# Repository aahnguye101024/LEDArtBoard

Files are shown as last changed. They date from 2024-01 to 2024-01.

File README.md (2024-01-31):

# LEDArtBoard
This project is an ESP32 that can control a huge array of leds in order to generate pixel art. With a single 12V input, you can power on an ESP32 and huge array of leds (at very low current draw for each led). It was intended as a gift for a friend, where I could upload an array of values with specific RGB codes to display that color in that specific led location on the array. It was also to test JLCPCB's new at the time feature to assemble PCBs for a super low cost.

# Main Board
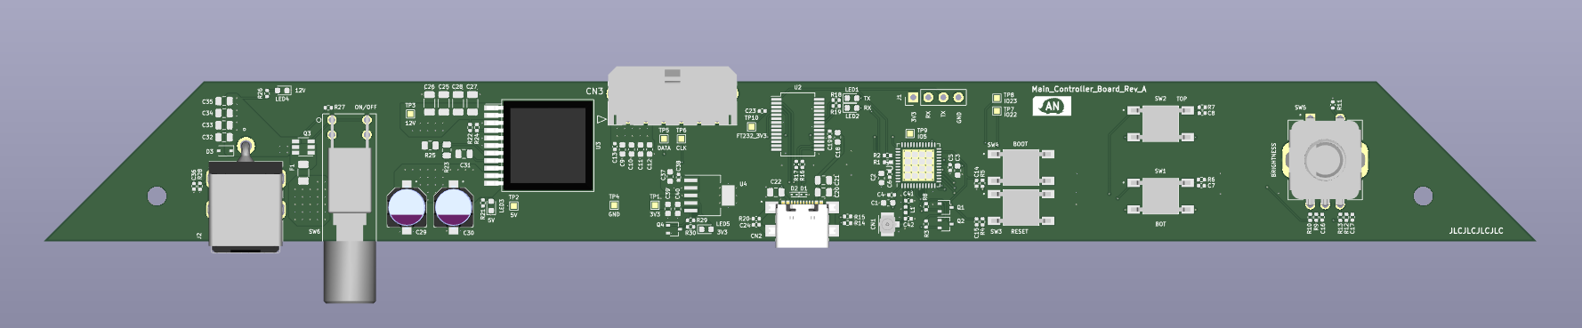
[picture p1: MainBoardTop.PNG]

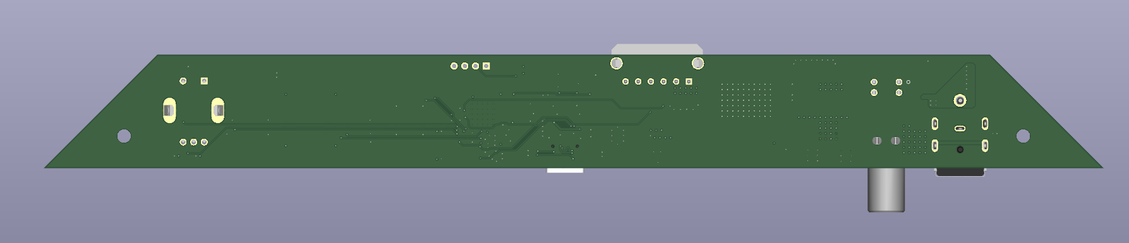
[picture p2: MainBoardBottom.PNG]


# LED Board
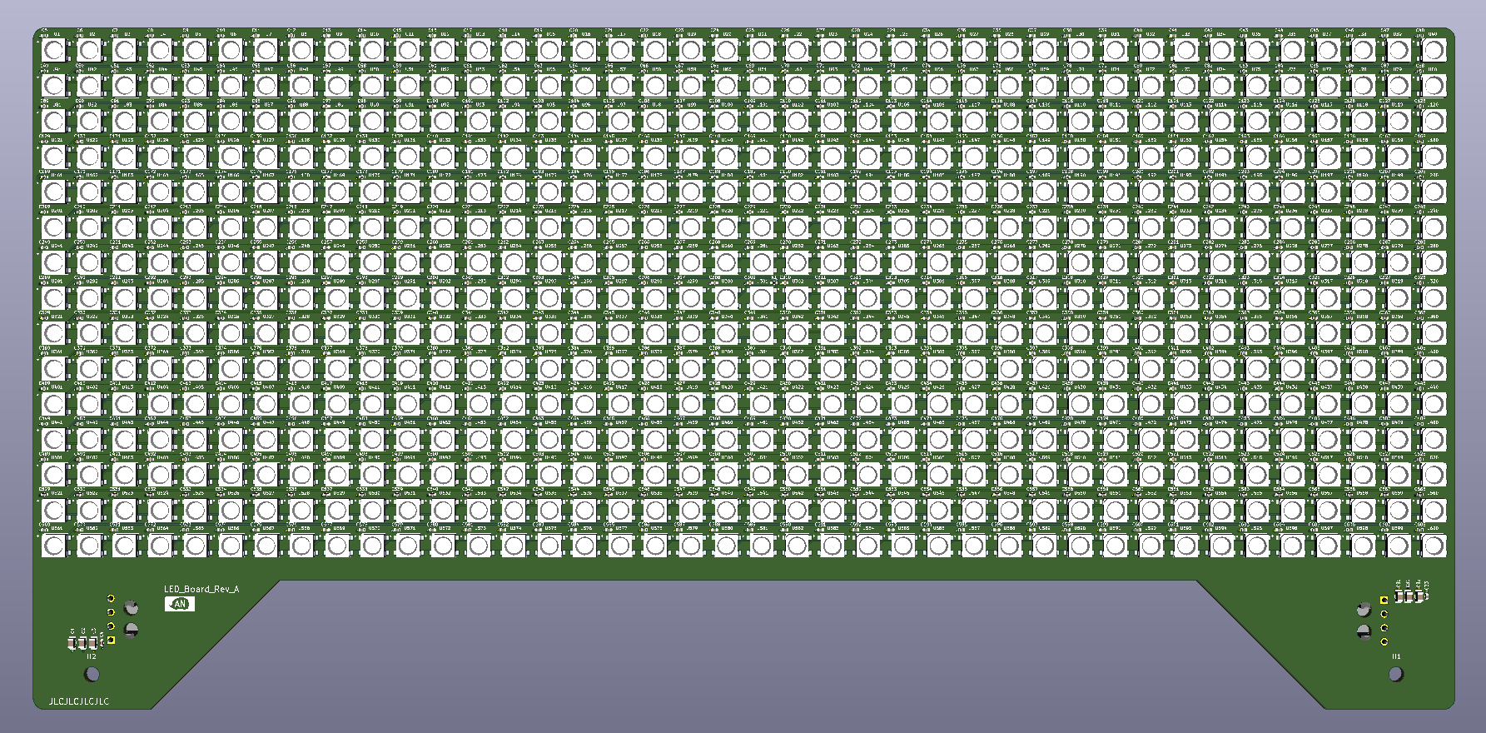
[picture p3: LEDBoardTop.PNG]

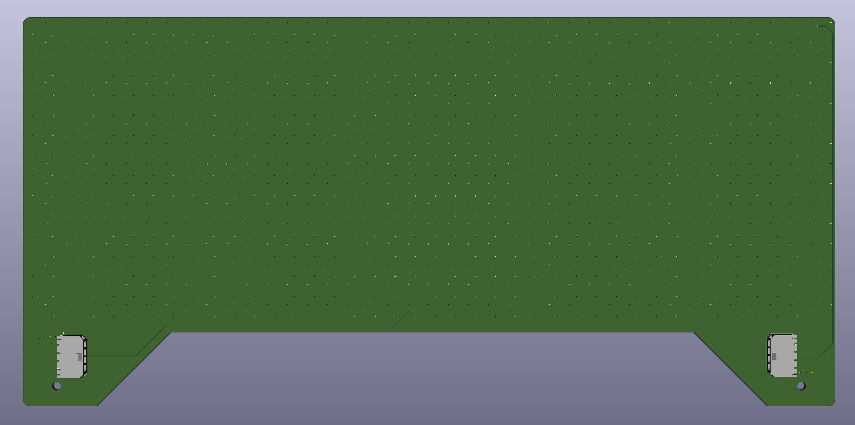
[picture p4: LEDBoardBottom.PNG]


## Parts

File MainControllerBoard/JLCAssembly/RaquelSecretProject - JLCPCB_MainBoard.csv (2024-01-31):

Comment | Designator | Footprint | JLCPCB Part #（optional）
ESP32-PICO-D4 | U1 | QFN-48_EP_7.0x7.0x0.5P | C193707
2.2uF | C1, C2, C3, C37, C39, C40, | 0603 | C23630
0.1uF | C4, C5, C6, C7, C8, C13, C14, C19, C23, C24, C36, C38, | 0402 | C1525
22uF | C9, C10, C11, C12, | 0603 | C59461
1uF | C15, | 0402 | C52923
0.01uF | C16, C17, | 0402 | C15195
4.7uF | C18, | 0603 | C19666
10uF | C20, C21, C22, C32, C33, C34, C35, | 0805 | C440198
22uF | C25, C26, C27, C28, | 1206 | C1934
0.47uF | C31, | 0805 | C13967
2.7pF | C41, | 0402 | C1561
10k | R3, R4, R8, R9, R10, R12, R13, | 0402 | C25744
4.7k | R5, R6, R7, R11, | 0402 | C25900
5.1k | R14, R15, | 0402 | C25905
330 | R18, R19, R20, R28, R30, | 0402 | C25104
100k | R22, R27, R29, | 0402 | C25741
22k | R24, | 0402 | C25768
0 | R1, R2, R16, R17, | 0402 | C17168

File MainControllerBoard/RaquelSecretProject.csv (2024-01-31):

Source: | C:\Users\AaronN\Desktop\Personal\PersonalProjects\RaquelSecretProject\MainControllerBoard\RaquelSecretProject.sch
Date: | 1/8/2022 8:56:27 PM
Tool: | Eeschema (5.1.10)-1
Generator: | C:\Program Files\KiCad\bin\scripting\plugins/AaronsFavoriteBOMScript.py
Component Count: | 113
Ref | Qnty | Value | Cmp name | Description | Manufacturer | Part Number
C1, C2, C3, C37, C39, C40, | 6 | 2.2uF | 2.2uF | CAP CER 2.2UF 10V X5R 0603 | Samsung Electro-Mechanics | 1276-1085-1-ND
C4, C5, C6, C7, C8, C13, C14, C19, C23, C24, C36, C38, | 12 | 0.1uF | 0.1uF | CAP CER 0.1UF 25V X5R 0402 | Samsung Electro-Mechanics | 1276-1043-1-ND
C9, C10, C11, C12, | 4 | 22uF | 22uF | CAP CER 22UF 10V X5R 0603 | Samsung Electro-Mechanics | 1276-1274-1-ND
C15, | 1 | 1uF | 1uF | CAP CER 1UF 10V X5R 0402 | Samsung Electro-Mechanics | 1276-1076-1-ND
C16, C17, | 2 | 0.01uF | 0.01uF | CAP CER 10000PF 16V X5R 0402 | KYOCERA AVX | 478-0402YD103KAT2ACT-ND
C18, | 1 | 4.7uF | 4.7uF | CAP CER 4.7UF 16V X5R 0603 | Samsung Electro-Mechanics | 1276-1784-1-ND
C20, C21, C22, C32, C33, C34, C35, | 7 | 10uF | 10uF | CAP CER 10UF 16V X5R 0805 | Samsung Electro-Mechanics | 1276-2893-1-ND
C25, C26, C27, C28, | 4 | 22uF_1206 | 22uF_1206 | CAP CER 22UF 25V X5R 1206 | Samsung Electro-Mechanics | 1276-3047-1-ND
C29, C30, | 2 | 270uF | 270uF | CAP ALUM POLY 270UF 20% 16V SMD | Panasonic Electronic Components | PCE5081CT-ND
C31, | 1 | 0.47uF | 0.47uF | CAP CER 0.47UF 25V X7R 0805 | Samsung Electro-Mechanics | 1276-1074-1-ND
C41, | 1 | 2.7pF | 2.7pF | CAP CER 2.7PF 50V C0G/NPO 0402 | YAGEO | 311-1005-1-ND
C42, | 1 | 2pF | 2pF | CAP CER 2PF 50V C0G/NPO 0402 | YAGEO | 311-1006-1-ND
CN1, | 1 | 1909763-1 | 1909763-1 | CONN UMCC JACK STR 50OHM SMD | TE Connectivity AMP Connectors | A118077CT-ND
CN2, | 1 | USB4110-GF-A_REVB | USB4110-GF-A_REVB | SMD USB 2.0-only Type-C Receptacle connector | GCT | 2073-USB4110-GF-A-1-ND
CN3, | 1 | 0436500603 | 0436500603 | Microfit CONN HEADER R/A 6POS 3MM | Molex | WM1874-ND
D1, D2, | 2 | ESD7951ST5G | ESD7951ST5G | TVS DIODE 5VWM 12.9VC SOD923 | onsemi | ESD7951ST5GOSCT-ND
D3, | 1 | ESD12VD3-TP | ESD12VD3-TP | TVS DIODE 12VWM 33VC SOD323 | Micro Commercial Co | ESD12VD3-TPMSCT-ND
F1, | 1 | C1F_7 | C1F_7 | FUSE 7.0A 125VAC FAST 1206 | Bel Fuse Inc. | 507-1888-1-ND
H1, H2, | 2 | MountingHole | MountingHole | Mounting Hole without connection
J1, | 1 | Conn_01x04 | Conn_01x04 | Generic connector, single row, 01x04, script generated (kicad-library-utils/schlib/autogen/connector/)
J2, | 1 | PJ-080BH | PJ-080BH | CONN PWR JACK 2.5X5.5MM SOLDER | CUI Devices | CP-080BHCT-ND
L1, | 1 | LQG15HS2N7S02D | LQG15HS2N7S02D | FIXED IND 2.7NH 800MA 150MOHM SM | Murata Electronics | 490-2615-1-ND
LED1, LED3, LED4, LED5, | 4 | SML-D12P8WT86 | SML-D12P8WT86 | LED GREEN DIFFUSED 0603 SMD | Rohm Semiconductor | 511-1579-1-ND
LED2, | 1 | SML-D12U1WT86 | SML-D12U1WT86 | LED RED DIFFUSED 0603 SMD | Rohm Semiconductor | SML-D12U1WT86CT-ND
Q1, Q2, | 2 | BC846W,115 | BC846W,115 | TRANS NPN 65V 100MA SOT323 | Nexperia USA Inc. | 1727-4850-1-ND
Q3, | 1 | SI3469DV-T1-E3 | SI3469DV-T1-E3 | MOSFET P-CH 20V 5A 6TSOP | Vishay Siliconix | SI3469DV-T1-E3CT-ND
Q4, | 1 | DMN67D8LW-13 | DMN67D8LW-13 | MOSFET N-CH 60V 240MA SOT323 | Diodes Incorporated | DMN67D8LW-13DICT-ND
R1, R2, R16, R17, | 4 | 0 | 0 | RES 0 OHM JUMPER 1/16W 0402 | Stackpole Electronics Inc | RMCF0402ZT0R00CT-ND
R3, R4, R8, R9, R10, R12, R13, | 7 | 10k | 10k | RES 10K OHM 1% 1/16W 0402 | Stackpole Electronics Inc | RMCF0402FT10K0CT-ND
R5, R6, R7, R11, | 4 | 4.7k | 4.7k | RES 4.7K OHM 1% 1/16W 0402 | Stackpole Electronics Inc | RMCF0402FT4K70CT-ND
R14, R15, | 2 | 5.1k | 5.1k | RES 5.1K OHM 1% 1/16W 0402 | YAGEO | 311-5.10KLRCT-ND
R18, R19, R20, R28, R30, | 5 | 330 | 330 | RES 330 OHM 1% 1/16W 0402 | YAGEO | 311-330LRCT-ND
R21, | 1 | 820 | 820 | RES 820 OHM 1% 1/16W 0402 | Stackpole Electronics Inc | RMCF0402FT820RCT-ND
R22, R27, R29, | 3 | 100k | 100k | RES SMD 100 KOHM 1% 1/16W 0402 | Delta Electronics/Cyntec | 2037-PFR05S-104-FNHCT-ND
R23, | 1 | 5.62k | 5.62k | RES 5.62K OHM 1% 1/8W 0805 | Stackpole Electronics Inc | RMCF0805FT5K62CT-ND
R24, | 1 | 22k | 22k | RES SMD 22K OHM 1% 1/16W 0402 | Bourns Inc. | CR0402-FX-2202GLFCT-ND
R25, | 1 | 1.07k | 1.07k | RES 1.07K OHM 1% 1/8W 0805 | YAGEO | 311-1.07KCRCT-ND
R26, | 1 | 3k | 3k | RES 3K OHM 1% 1/16W 0402 | Stackpole Electronics Inc | RMCF0402FT3K00CT-ND
SW1, SW2, SW3, SW4, | 4 | FSM2JSMAA | FSM2JSMAA | SMD Momentary PushButton | FSM2JSMAA | 450-3355-ND
SW5, | 1 | PEC11R-4020F-S0024 | PEC11R-4020F-S0024 | ROTARY ENCODER MECHANICAL 24PPR | Bourns Inc. | PEC11R-4020F-S0024-ND
SW6, | 1 | PB400EEQR1BLK | PB400EEQR1BLK | Pushbutton Switch DPST Standard Through Hole, Right Angle | E-Switch | Ologic
TP1, | 1 | 3V3 | TestPoint | test point
TP2, | 1 | 5V | TestPoint | test point
TP3, | 1 | 12V | TestPoint | test point
TP4, | 1 | GND | TestPoint | test point
TP5, | 1 | DATA | TestPoint | test point
TP6, | 1 | CLK | TestPoint | test point
TP7, | 1 | IO22 | TestPoint | test point
TP8, | 1 | IO23 | TestPoint | test point
TP9, | 1 | IO5 | TestPoint | test point
TP10, | 1 | FT232_3V3 | TestPoint | test point
U1, | 1 | ESP32-PICO-D4 | ESP32-PICO-D4 |  | Espressif Systems | 1904-1029-1-ND
U2, | 1 | FT232RL | FT232RL | USB to Serial Interface, SSOP-28 | Ologic | Ologic
U3, | 1 | LMZ13610 | LMZ13610 | DC DC CONVERTER 0.8-6V 50W | Texas Instruments | Ologic
U4, | 1 | MCP1826T-3302E_DC | MCP1826T-3302E_DC | IC REG LINEAR 3.3V 1A SOT223-5 | Microchip Technology | Ologic

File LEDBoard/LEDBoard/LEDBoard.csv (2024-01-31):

Source: | C:\Users\AaronN\Desktop\Personal\PersonalProjects\RaquelSecretProject\LEDBoard\LEDBoard\LEDBoard.sch
Date: | 1/9/2022 12:14:57 AM
Tool: | Eeschema (5.1.10)-1
Generator: | C:\Program Files\KiCad\bin\scripting\plugins/AaronsFavoriteBOMScript.py
Component Count: | 1213
Ref | Qnty | Value | Cmp name | Description | Manufacturer | Part Number
C1, C2, C3, C30, C31, C32, | 6 | 10uF | 10uF | CAP CER 10UF 16V X5R 0805 | Samsung Electro-Mechanics | 1276-2893-1-ND
C4, C33, | 2 | 0.1uF | 0.1uF | CAP CER 0.1UF 25V X5R 0402 | Samsung Electro-Mechanics | 1276-1043-1-ND
C5, C6, C7, C8, C9, C10, C11, C12, C13, C14, C15, C16, C17, C18, C19, C20, C21, C22, C23, C24, C25, C26, C27, C28, C29, C34, C35, C36, C37, C38, C39, C40, C41, C42, C43, C44, C45, C46, C47, C48, C49, C50, C51, C52, C53, C54, C55, C56, C57, C58, C59, C60, C61, C62, C63, C64, C65, C66, C67, C68, C69, C70, C71, C72, C73, C74, C75, C76, C77, C78, C79, C80, C81, C82, C83, C84, C85, C86, C87, C88, C89, C90, C91, C92, C93, C94, C95, C96, C97, C98, C99, C100, C101, C102, C103, C104, C105, C106, C107, C108, C109, C110, C111, C112, C113, C114, C115, C116, C117, C118, C119, C120, C121, C122, C123, C124, C125, C126, C127, C128, C129, C130, C131, C132, C133, C134, C135, C136, C137, C138, C139, C140, C141, C142, C143, C144, C145, C146, C147, C148, C149, C150, C151, C152, C153, C154, C155, C156, C157, C158, C159, C160, C161, C162, C163, C164, C165, C166, C167, C168, C169, C170, C171, C172, C173, C174, C175, C176, C177, C178, C179, C180, C181, C182, C183, C184, C185, C186, C187, C188, C189, C190, C191, C192, C193, C194, C195, C196, C197, C198, C199, C200, C201, C202, C203, C204, C205, C206, C207, C208, C209, C210, C211, C212, C213, C214, C215, C216, C217, C218, C219, C220, C221, C222, C223, C224, C225, C226, C227, C228, C229, C230, C231, C232, C233, C234, C235, C236, C237, C238, C239, C240, C241, C242, C243, C244, C245, C246, C247, C248, C249, C250, C251, C252, C253, C254, C255, C256, C257, C258, C259, C260, C261, C262, C263, C264, C265, C266, C267, C268, C269, C270, C271, C272, C273, C274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 | 600 | 1uF | 1uF | CAP CER 1UF 10V X5R 0402 | Samsung Electro-Mechanics | 1276-1076-1-ND
CN1, CN2, | 2 | 0436500400 | 0436500400 | Microfit R/A CONN HEADER R/A 4POS 3MM | Molex | WM1862-ND
H1, H2, | 2 | MountingHole | MountingHole | Mounting Hole without connection
R1, | 1 | 0 | 0 | RES 0 OHM JUMPER 1/16W 0402 | Stackpole Electronics Inc | RMCF0402ZT0R00CT-ND
U1, U2, U3, U4, U5, U6, U7, U8, U9, U10, U11, U12, U13, U14, U15, U16, U17, U18, U19, U20, U21, U22, U23, U24, U25, U26, U27, U28, U29, U30, U31, U32, U33, U34, U35, U36, U37, U38, U39, U40, U41, U42, U43, U44, U45, U46, U47, U48, U49, U50, U51, U52, U53, U54, U55, U56, U57, U58, U59, U60, U61, U62, U63, U64, U65, U66, U67, U68, U69, U70, U71, U72, U73, U74, U75, U76, U77, U78, U79, U80, U81, U82, U83, U84, U85, U86, U87, U88, U89, U90, U91, U92, U93, U94, U95, U96, U97, U98, U99, U100, U101, U102, U103, U104, U105, U106, U107, U108, U109, U110, U111, U112, U113, U114, U115, U116, U117, U118, U119, U120, U121, U122, U123, U124, U125, U126, U127, U128, U129, U130, U131, U132, U133, U134, U135, U136, U137, U138, U139, U140, U141, U142, U143, U144, U145, U146, U147, U148, U149, U150, U151, U152, U153, U154, U155, U156, U157, U158, U159, U160, U161, U162, U163, U164, U165, U166, U167, U168, U169, U170, U171, U172, U173, U174, U175, U176, U177, U178, U179, U180, U181, U182, U183, U184, U185, U186, U187, U188, U189, U190, U191, U192, U193, U194, U195, U196, U197, U198, U199, U200, U201, U202, U203, U204, U205, U206, U207, U208, U209, U210, U211, U212, U213, U214, U215, U216, U217, U218, U219, U220, U221, U222, U223, U224, U225, U226, U227, U228, U229, U230, U231, U232, U233, U234, U235, U236, U237, U238, U239, U240, U241, U242, U243, U244, U245, U246, U247, U248, U249, U250, U251, U252, U253, U254, U255, U256, U257, U258, U259, U260, U261, U262, U263, U264, U265, U266, U267, U268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 | 600 | WS2812B | WS2812B | JLCPCB SMD,5x5mm Light Emitting Diodes (LED) ROHS | Worldsemi | C2761795

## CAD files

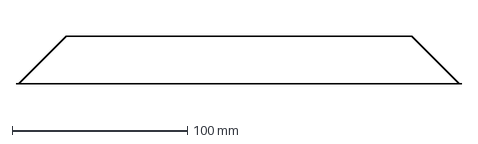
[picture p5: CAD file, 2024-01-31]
MainControllerBoard/MainControllerBoard.dxf
254.0 x 26.9 mm

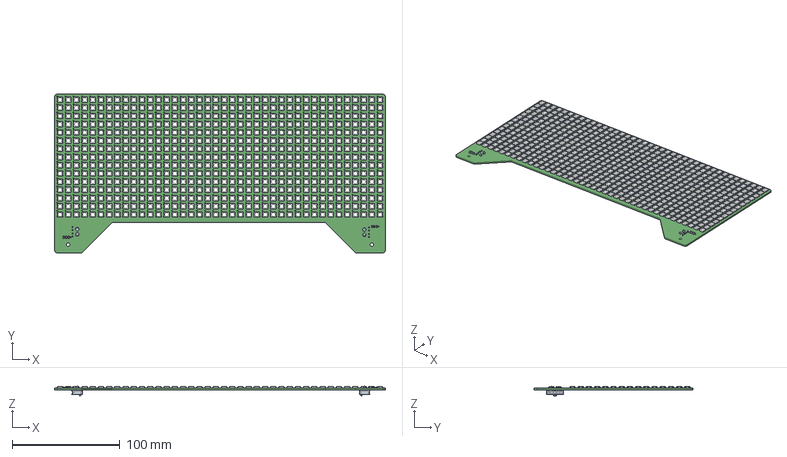
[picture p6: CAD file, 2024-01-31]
LEDBoard/LEDBoard/LEDBoard.step
307.3 x 147.3 x 8.90 mm

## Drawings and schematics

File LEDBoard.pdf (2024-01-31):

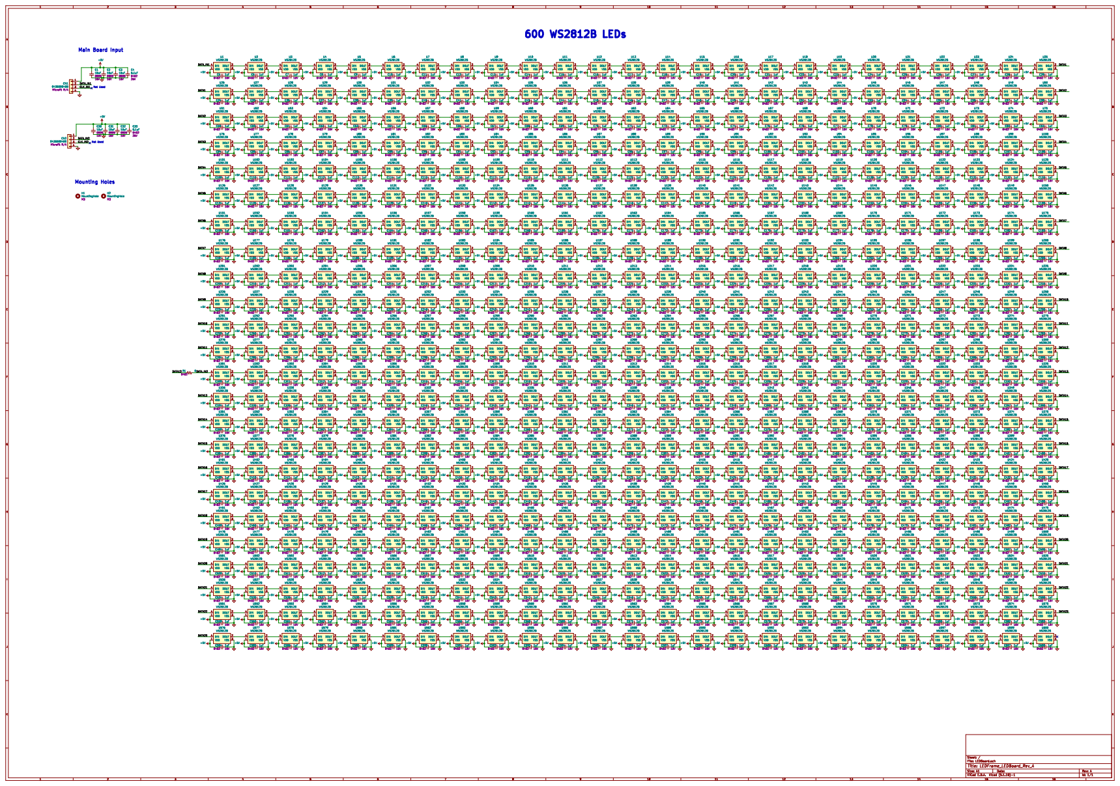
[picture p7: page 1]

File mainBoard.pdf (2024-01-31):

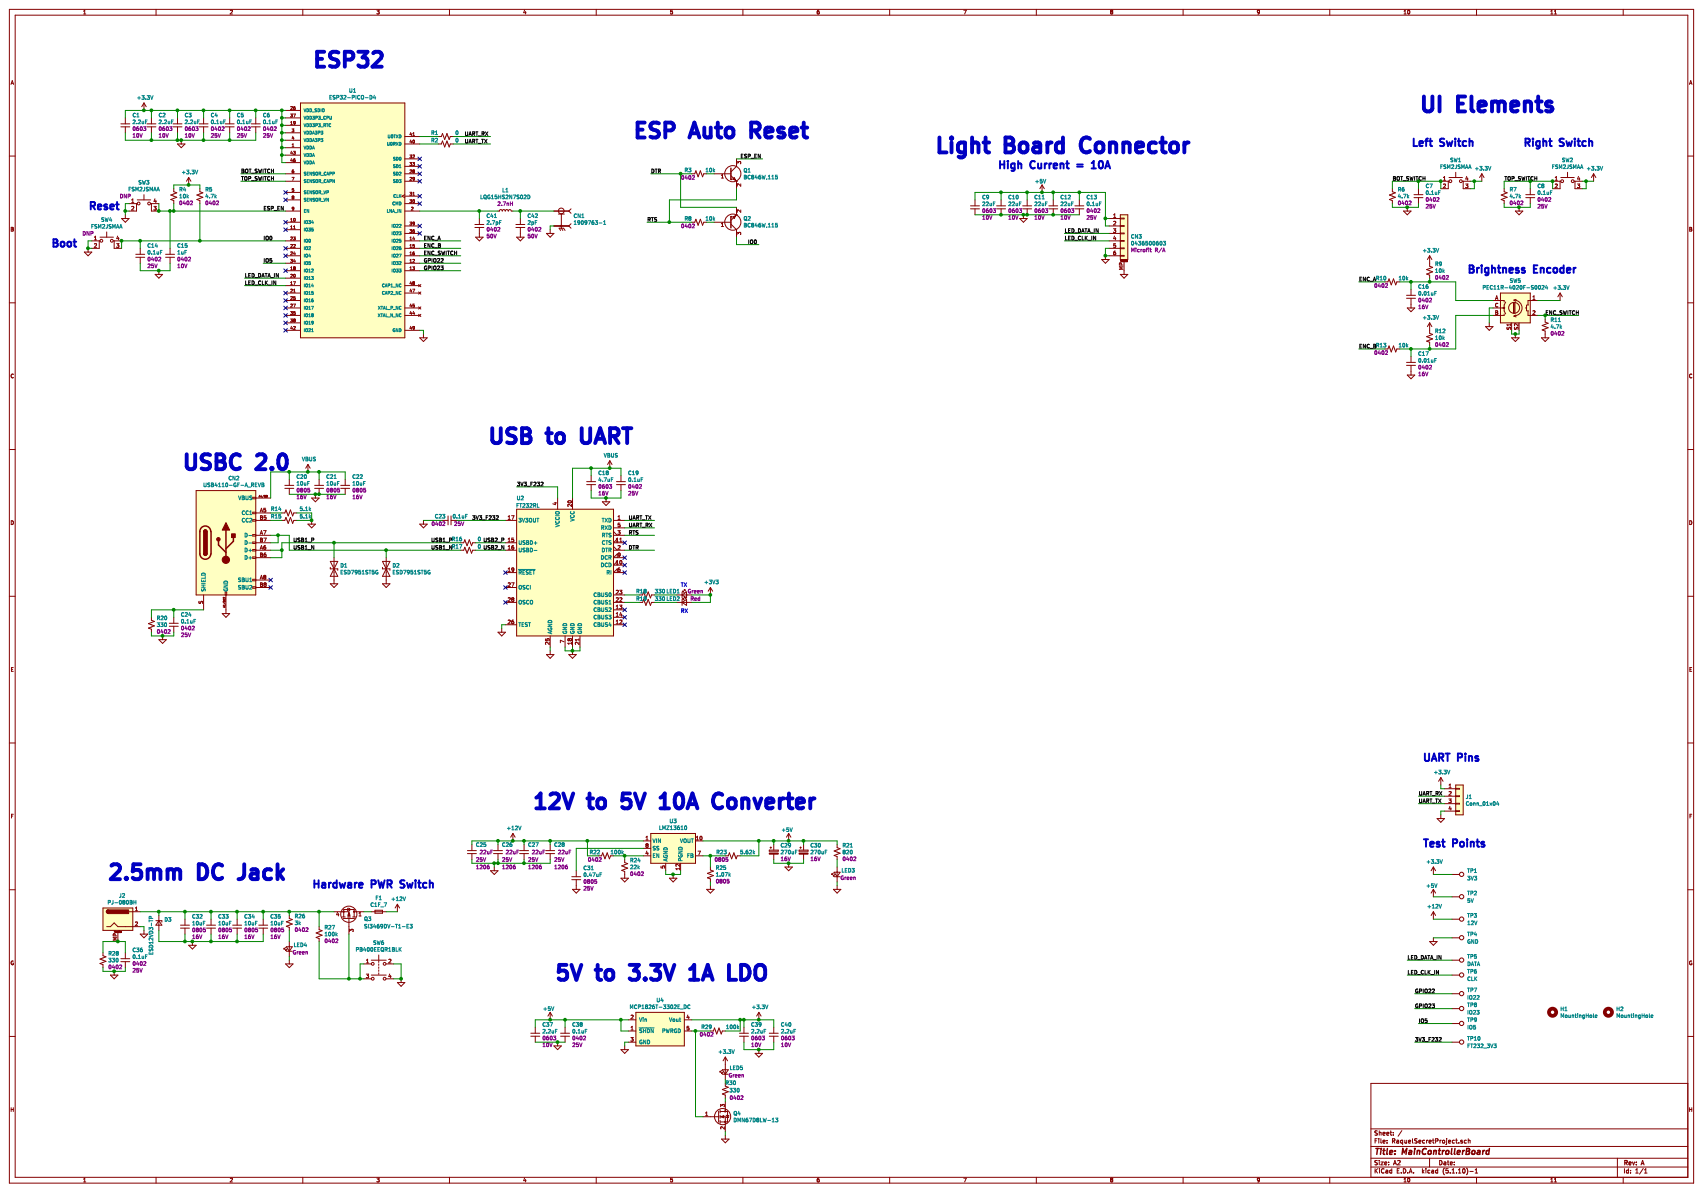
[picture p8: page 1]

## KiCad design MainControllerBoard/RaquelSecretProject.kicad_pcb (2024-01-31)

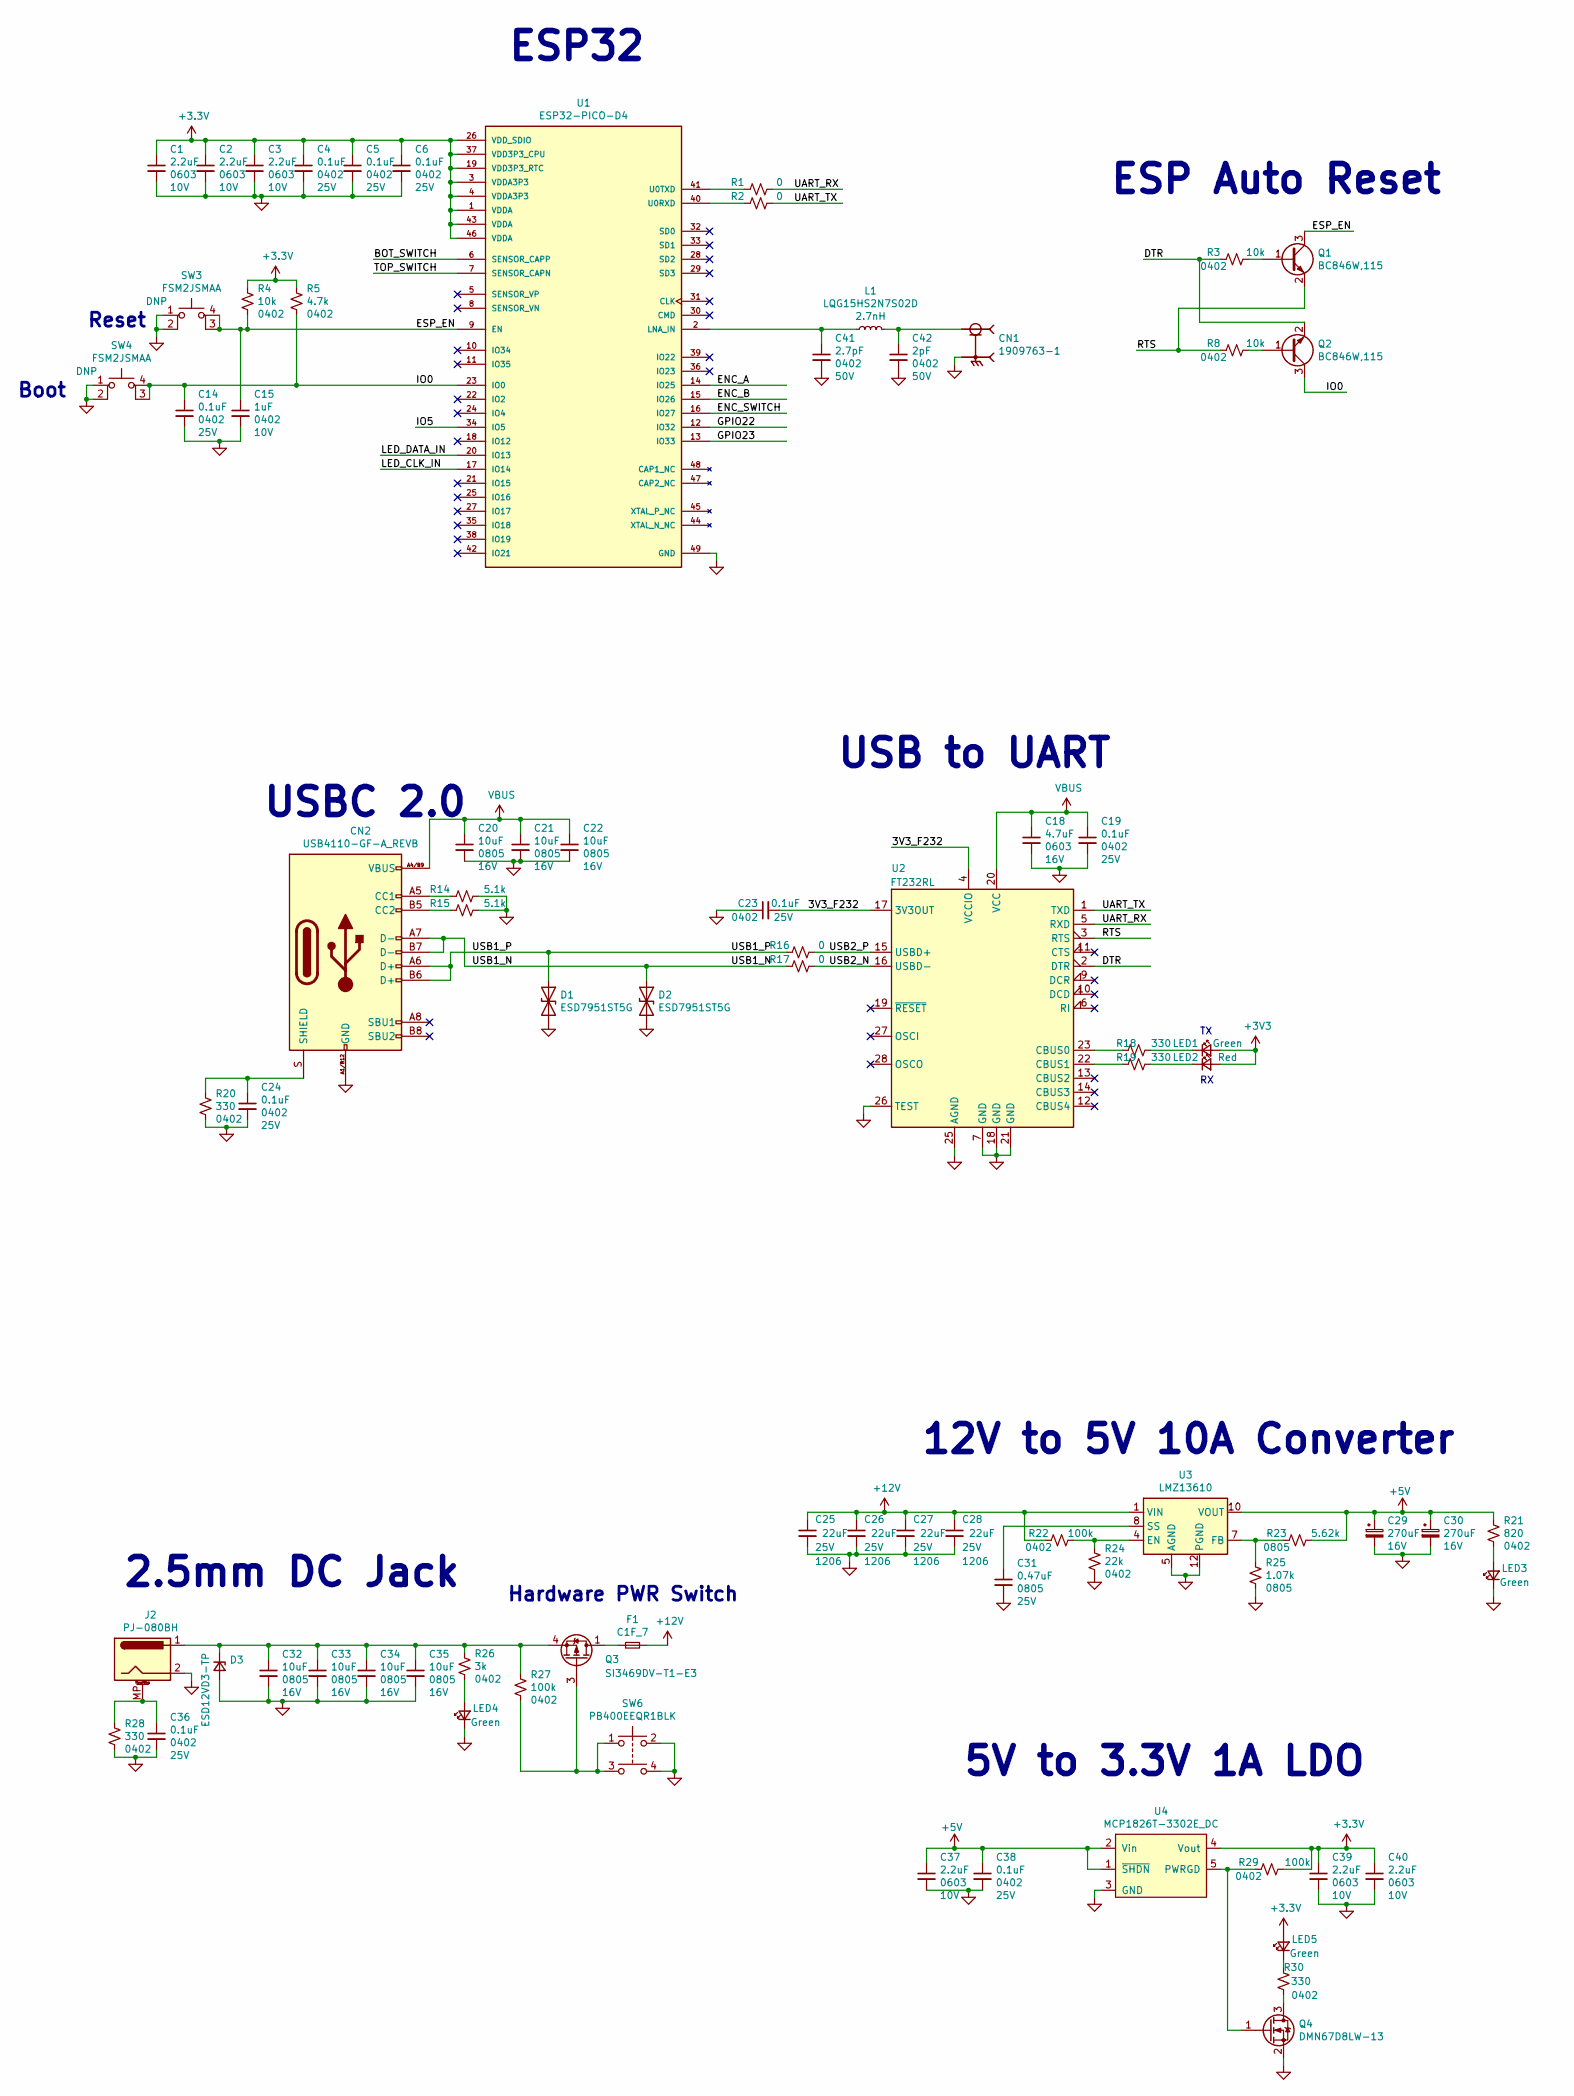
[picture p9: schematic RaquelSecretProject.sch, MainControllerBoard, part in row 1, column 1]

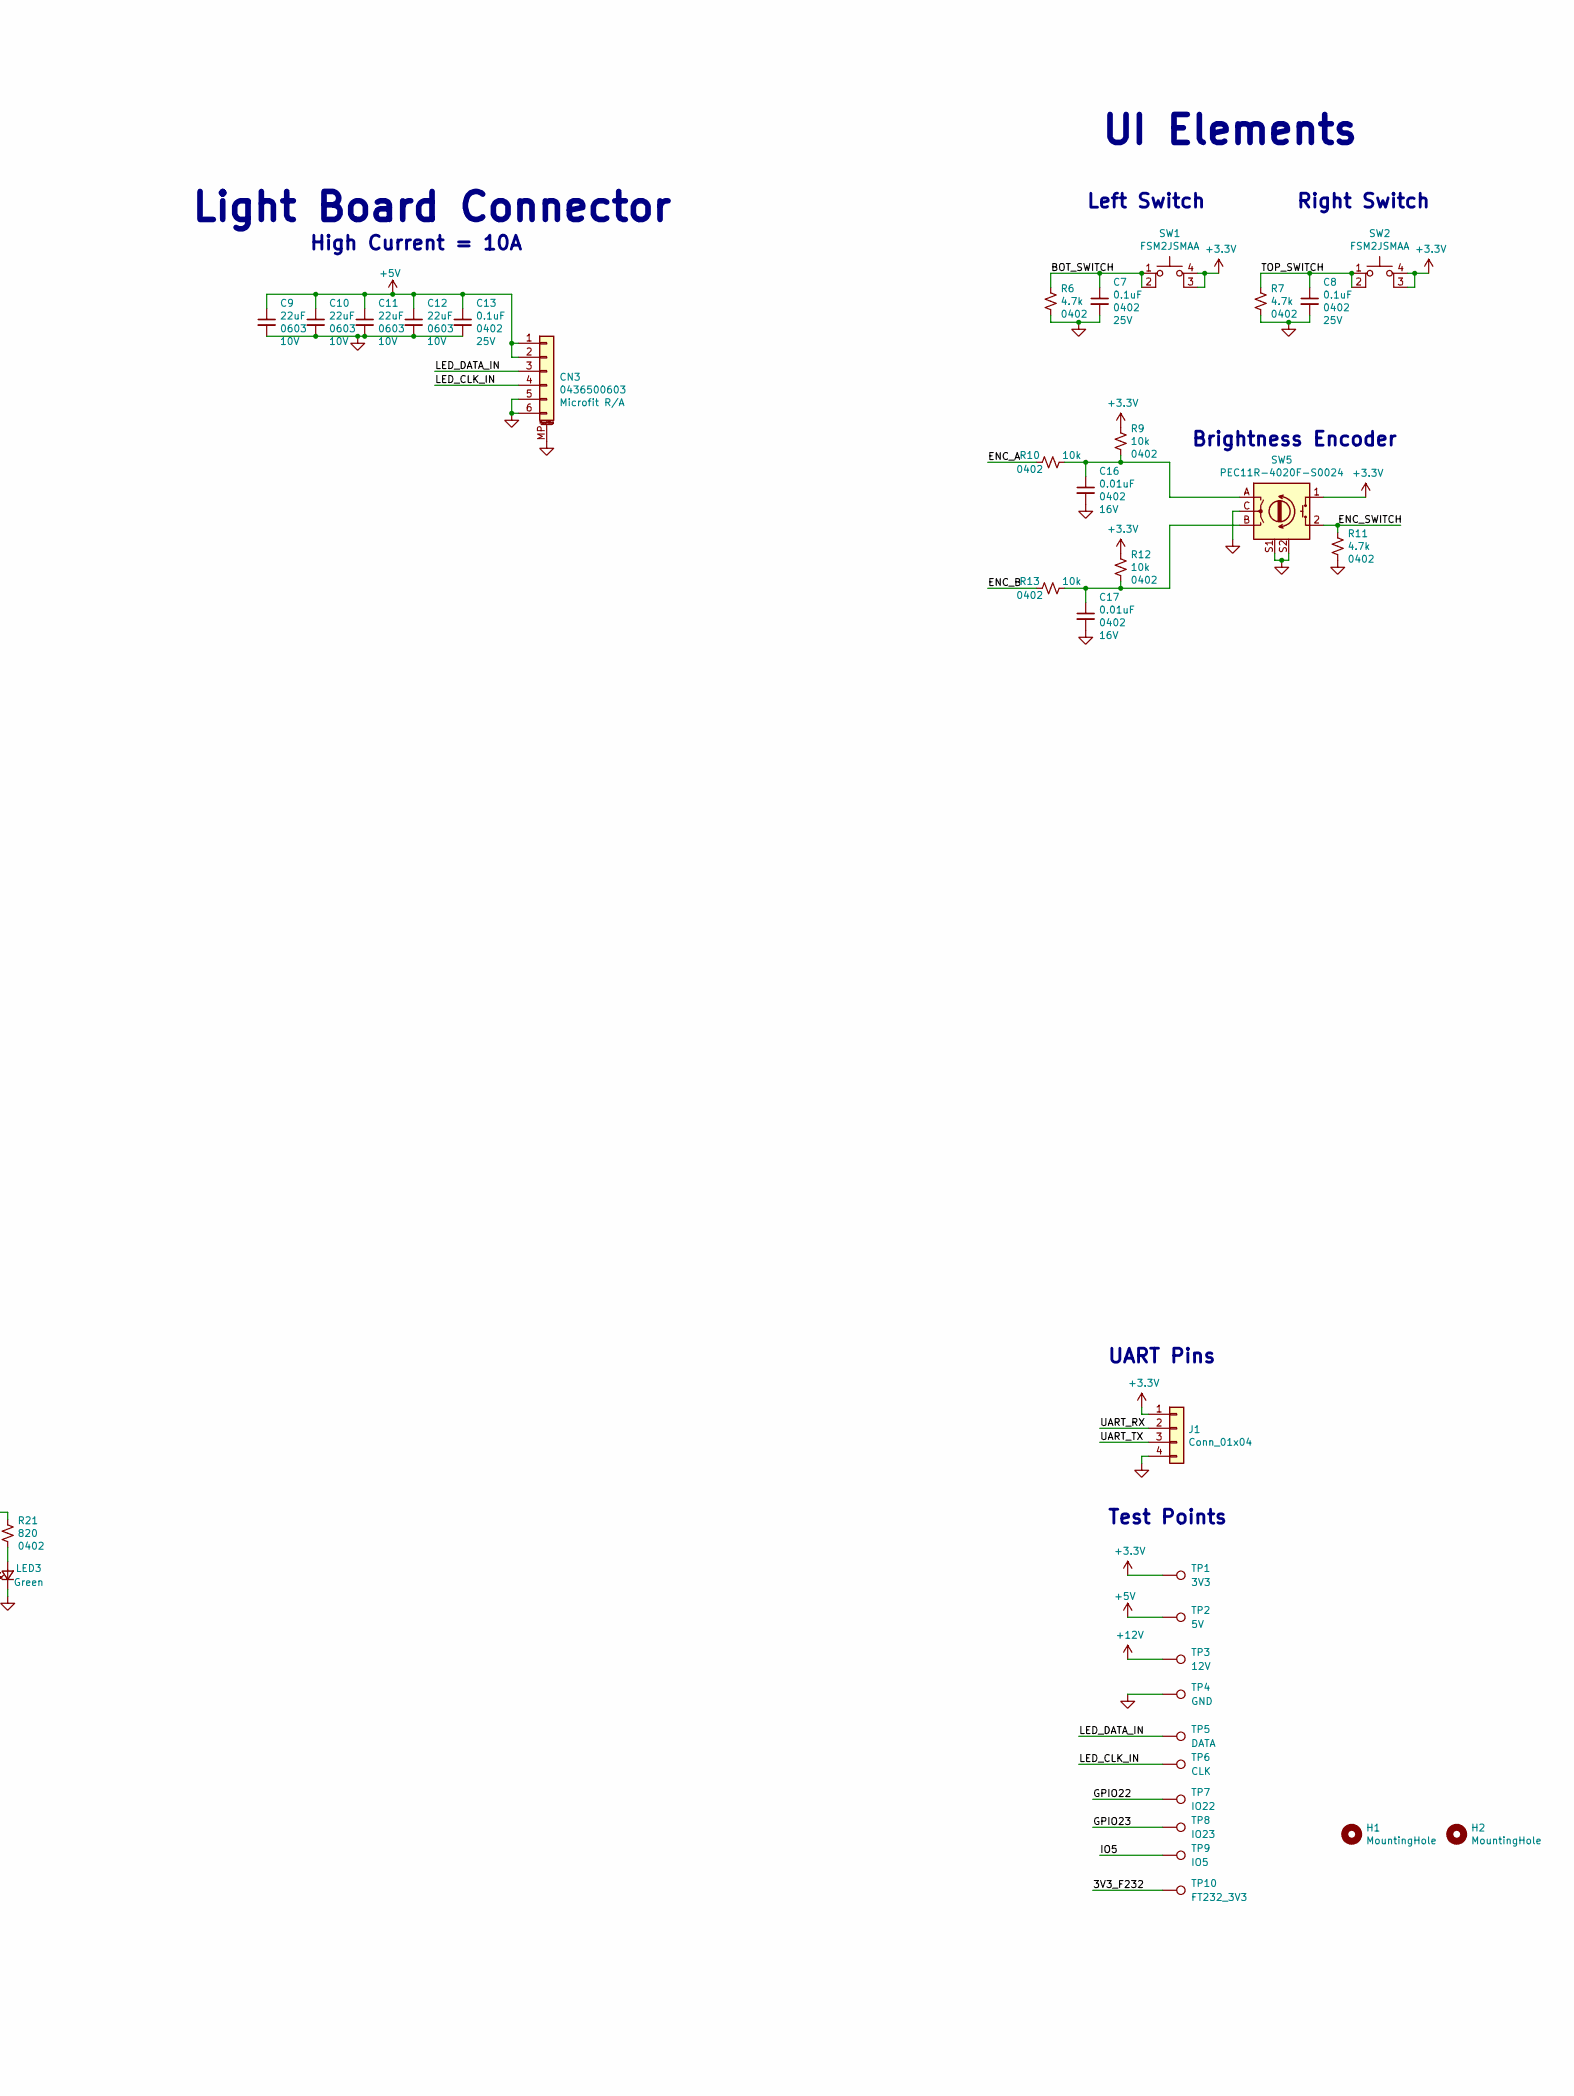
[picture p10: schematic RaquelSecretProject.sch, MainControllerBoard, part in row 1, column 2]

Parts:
C1, C2, C3, C37, C39, C40: 2.2uF; C_0603_1608Metric; Voltage 10V; Part Number 1276-1085-1-ND
C4, C5, C6, C7, C8, C13, C14, C19, C23, C24, C36, C38: 0.1uF; C_0402_1005Metric; Voltage 25V; Part Number 1276-1043-1-ND
C9, C10, C11, C12: 22uF; C_0603_1608Metric; Voltage 10V; Part Number 1276-1274-1-ND
C15: 1uF; C_0402_1005Metric; Voltage 10V; Part Number 1276-1076-1-ND
C16, C17: 0.01uF; C_0402_1005Metric; Voltage 16V; Part Number 478-0402YD103KAT2ACT-ND
C18: 4.7uF; C_0603_1608Metric; Voltage 16V; Part Number 1276-1784-1-ND
C20, C21, C22, C32, C33, C34, C35: 10uF; C_0805_2012Metric; Voltage 16V; Part Number 1276-2893-1-ND
C25, C26, C27, C28: 22uF_1206; C_1206_3216Metric; Voltage 25V; Part Number 1276-3047-1-ND
C29, C30: 270uF; CAP_16SVPG270M; Voltage 16V; Part Number PCE5081CT-ND
C31: 0.47uF; C_0805_2012Metric; Voltage 25V; Part Number 1276-1074-1-ND
C41: 2.7pF; C_0402_1005Metric; Voltage 50V; Part Number 311-1005-1-ND
C42: 2pF; C_0402_1005Metric; Voltage 50V; Part Number 311-1006-1-ND
CN1: 1909763-1; TE_1909763-1; Part Number A118077CT-ND
CN2: USB4110-GF-A_REVB; GCT_USB4110-GF-A_REVB; Part Number 2073-USB4110-GF-A-1-ND
CN3: 0436500603; 436500603; Part Number WM1874-ND
D1, D2: ESD7951ST5G; D_SOD-923; Part Number ESD7951ST5GOSCT-ND
D3: ESD12VD3-TP; D_SOD-323; Part Number ESD12VD3-TPMSCT-ND
F1: C1F_7; Fuse_1206_3216Metric; Part Number 507-1888-1-ND
H1, H2: MountingHole; MountingHole_3.2mm_M3_ISO7380
J1: Conn_01x04; PinHeader_1x04_P2.54mm_Vertical
J2: PJ-080BH; CUI_PJ-080BH; Part Number CP-080BHCT-ND
L1: LQG15HS2N7S02D; L_0402_1005Metric; Part Number 490-2615-1-ND
LED1, LED3, LED4, LED5: SML-D12P8WT86; LED_0603_1608Metric; Part Number 511-1579-1-ND
LED2: SML-D12U1WT86; LED_0603_1608Metric; Part Number SML-D12U1WT86CT-ND
Q1, Q2: BC846W,115; SOT-323_SC-70; Part Number 1727-4850-1-ND
Q3: SI3469DV-T1-E3; TSOT-23-6; Part Number SI3469DV-T1-E3CT-ND
Q4: DMN67D8LW-13; SOT-323_SC-70; Part Number DMN67D8LW-13DICT-ND
R1, R2, R16, R17: 0; R_0402_1005Metric; Part Number RMCF0402ZT0R00CT-ND
R3, R4, R8, R9, R10, R12, R13: 10k; R_0402_1005Metric; Part Number RMCF0402FT10K0CT-ND
R5, R6, R7, R11: 4.7k; R_0402_1005Metric; Part Number RMCF0402FT4K70CT-ND
R14, R15: 5.1k; R_0402_1005Metric; Part Number 311-5.10KLRCT-ND
R18, R19, R20, R28, R30: 330; R_0402_1005Metric; Part Number 311-330LRCT-ND
R21: 820; R_0402_1005Metric; Part Number RMCF0402FT820RCT-ND
R22, R27, R29: 100k; R_0402_1005Metric; Part Number 2037-PFR05S-104-FNHCT-ND
R23: 5.62k; R_0805_2012Metric; Part Number RMCF0805FT5K62CT-ND
R24: 22k; R_0402_1005Metric; Part Number CR0402-FX-2202GLFCT-ND
R25: 1.07k; R_0805_2012Metric; Part Number 311-1.07KCRCT-ND
R26: 3k; R_0402_1005Metric; Part Number RMCF0402FT3K00CT-ND
SW1, SW2, SW3, SW4: FSM2JSMAA; SW_2-1437565-8; Part Number 450-3355-ND
SW5: PEC11R-4020F-S0024; Part Number PEC11R-4020F-S0024-ND
SW6: PB400EEQR1BLK; Part Number Ologic
TP1: 3V3; CurrentTestPoint
TP2: 5V; CurrentTestPoint
TP3: 12V; CurrentTestPoint
TP4: GND; CurrentTestPoint
TP5: DATA; CurrentTestPoint
TP6: CLK; CurrentTestPoint
TP7: IO22; CurrentTestPoint
TP8: IO23; CurrentTestPoint
TP9: IO5; CurrentTestPoint
TP10: FT232_3V3; CurrentTestPoint
U1: ESP32-PICO-D4; QFN-48-1EP_7x7mm_P0.5mm_EP5.3x5.3mm_ThermalVias; Part Number 1904-1029-1-ND
U2: FT232RL; SSOP-28_5.3x10.2mm_P0.65mm; Part Number Ologic
U3: LMZ13610; Texas_NDY0011A; Part Number Ologic
U4: MCP1826T-3302E_DC; SOT-223-6_TabPin3; Part Number Ologic

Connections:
+5V: C9.1, C10.1, C11.1, C12.1, C13.1, C29.1, C30.1, C37.1, C38.1, CN3.1, CN3.2, R21.1, R23.1, TP2.1, U3.10 (VOUT), U3.11 (VOUT), U4.1 (~SHDN~), U4.2 (Vin)
+12V: C25.1, C26.1, C27.1, C28.1, F1.2, R22.2, TP3.1, U3.1 (VIN), U3.2 (VIN)
/3V3_F232: C23.2, TP10.1, U2.4 (VCCIO), U2.17 (3V3OUT)
/BOT_SWITCH: C7.1, R6.1, SW1.1, SW1.2, U1.6 (SENSOR_CAPP)
/DTR: Q2.2 (E), R3.2, U2.2 (DTR)
/ENC_A: R10.2, U1.14 (IO25)
/ENC_B: R13.2, U1.15 (IO26)
/ENC_SWITCH: R11.1, SW5.2, U1.16 (IO27)
/ESP_EN: C15.1, Q1.3 (C), R4.2, SW3.3 (K), SW3.4 (A), U1.9 (EN)
/GPIO22: TP7.1, U1.12 (IO32)
/GPIO23: TP8.1, U1.13 (IO33)
/IO0: C14.1, Q2.3 (C), R5.2, SW4.3 (K), SW4.4 (A), U1.23 (IO0)
/IO5: TP9.1, U1.34 (IO5)
/LED_CLK_IN: CN3.4, TP6.1, U1.17 (IO14)
/LED_DATA_IN: CN3.3, TP5.1, U1.20 (IO13)
/RTS: Q1.2 (E), R8.2, U2.3 (RTS)
/TOP_SWITCH: C8.1, R7.1, SW2.1, SW2.2, U1.7 (SENSOR_CAPN)
/UART_RX: J1.2, R1.1, U2.5 (RXD)
/UART_TX: J1.3, R2.1, U2.1 (TXD)
/USB1_N: CN2.A7 (D-), CN2.B7 (D-), D2.1 (A1), R17.2
/USB1_P: CN2.A6 (D+), CN2.B6 (D+), D1.1 (A1), R16.2
/USB2_N: R17.1, U2.16 (USBD-)
/USB2_P: R16.1, U2.15 (USBD+)
GND: C1.2, C2.2, C3.2, C4.2, C5.2, C6.2, C7.2, C8.2, C9.2, C10.2, C11.2, C12.2, C13.2, C14.2, C15.2, C16.2, C17.2, C18.2, C19.2, C20.2, C21.2, C22.2, C23.1, C24.2, C25.2, C26.2, C27.2, C28.2, C29.2, C30.2, C31.2, C32.2, C33.2, C34.2, C35.2, C36.2, C37.2, C38.2, C39.2, C40.2, C41.2, C42.2, CN1.2, CN1.3, CN2.A1/B12 (GND), CN2.B1/A12 (GND), CN3.5, CN3.6, CN3.MP (MountPin), D1.2 (A2), D2.2 (A2), D3.2 (A), J1.4, J2.2, LED3.1 (K), LED4.1 (K), Q4.2 (S), R6.2, R7.2, R11.2, R14.2, R15.2, R20.2, R24.2, R25.2, R28.2, SW3.1, SW3.2, SW4.1, SW4.2, SW5.C, SW5.S1 (Shield), SW5.S2 (Shield), SW6.2, SW6.4, TP4.1, U1.49 (GND), U2.7 (GND), U2.18 (GND), U2.21 (GND), U2.25 (AGND), U2.26 (TEST), U3.3 (AGND), U3.5 (AGND), U3.6 (AGND), U3.12 (PGND), U4.3 (GND)
unnamed: C16.1, R9.2, R10.1, SW5.A
unnamed: C17.1, R12.2, R13.1, SW5.B
unnamed: C24.1, CN2.S (SHIELD), R20.1
unnamed: C31.1, U3.8 (SS)
unnamed: C32.1, C33.1, C34.1, C35.1, D3.1 (K), J2.1, Q3.4 (S), R26.1, R27.1
unnamed: C36.1, J2.MP (MountPin), R28.1
unnamed: C41.1, L1.1, U1.2 (LNA_IN)
unnamed: C42.1, CN1.1, L1.2
unnamed: CN2.A5 (CC1), R14.1
unnamed: CN2.B5 (CC2), R15.1
unnamed: F1.1, Q3.1 (D), Q3.2 (D), Q3.5 (D), Q3.6 (D)
unnamed: LED1.1 (K), R18.1
unnamed: LED2.1 (K), R19.1
unnamed: LED3.2 (A), R21.2
unnamed: LED4.2 (A), R26.2
unnamed: LED5.1 (K), R30.2
unnamed: Q1.1 (B), R3.1
unnamed: Q2.1 (B), R8.1
unnamed: Q3.3 (G), R27.2, SW6.1, SW6.3
unnamed: Q4.1 (G), R29.1, U4.5 (PWRGD)
unnamed: Q4.3 (D), R30.1
unnamed: R1.2, U1.41 (U0TXD)
unnamed: R2.2, U1.40 (U0RXD)
unnamed: R18.2, U2.23 (CBUS0)
unnamed: R19.2, U2.22 (CBUS1)
unnamed: R22.1, R24.1, U3.4 (EN)
unnamed: R23.2, R25.1, U3.7 (FB)
VBUS: C18.1, C19.1, C20.1, C21.1, C22.1, CN2.A4/B9 (VBUS), CN2.B4/A9 (VBUS), U2.20 (VCC)

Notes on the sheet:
USB to UART
USBC 2.0
ESP32
12V to 5V 10A Converter
5V to 3.3V 1A LDO
2.5mm DC Jack
ESP Auto Reset
Reset
Boot
Brightness Encoder
Left Switch
Right Switch
Light Board Connector
High Current = 10A
Hardware PWR Switch
Test Points
UART Pins
UI Elements

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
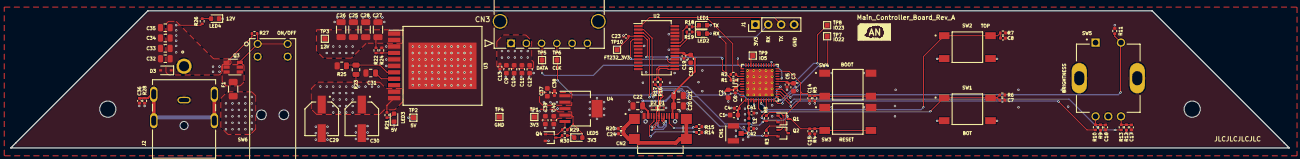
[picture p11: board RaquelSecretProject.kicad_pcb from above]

Board: 4 copper layers, 251.2 x 26.9 mm, 113 parts (0 on the bottom side), 53 nets.

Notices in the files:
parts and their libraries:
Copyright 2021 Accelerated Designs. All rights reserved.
